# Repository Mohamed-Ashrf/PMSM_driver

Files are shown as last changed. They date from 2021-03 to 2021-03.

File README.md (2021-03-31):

# PMSM_driver
micro-controller based driver for PMSM and BLDC motors
# PMSM_driver
micro-controller based driver for PMSM and BLDC motors

# main components 
  1- STM32f446RE as main micro controller.
  2- DRV8323H as the moset driver and integrated curent sensor.
  3- CSD19534Q5A, a 100V rated mosfets.
  
# main functions
this driver is mainly a three phase inverter, so it can be used to drive ay three phase machie within the range of 60V or less (maily for 48V systems), it also can be used as an H-bridge by utilizig onlt two phases, the main PCB has an interface for encoder to be used in acuators, the driver also provides 12V 1.5A output.

# BETA
the hardware is still under testig so soon the main version will be uploaded plus the code for interfacing with the driver, mainly Six-step commutation ad FOC will be implemented.

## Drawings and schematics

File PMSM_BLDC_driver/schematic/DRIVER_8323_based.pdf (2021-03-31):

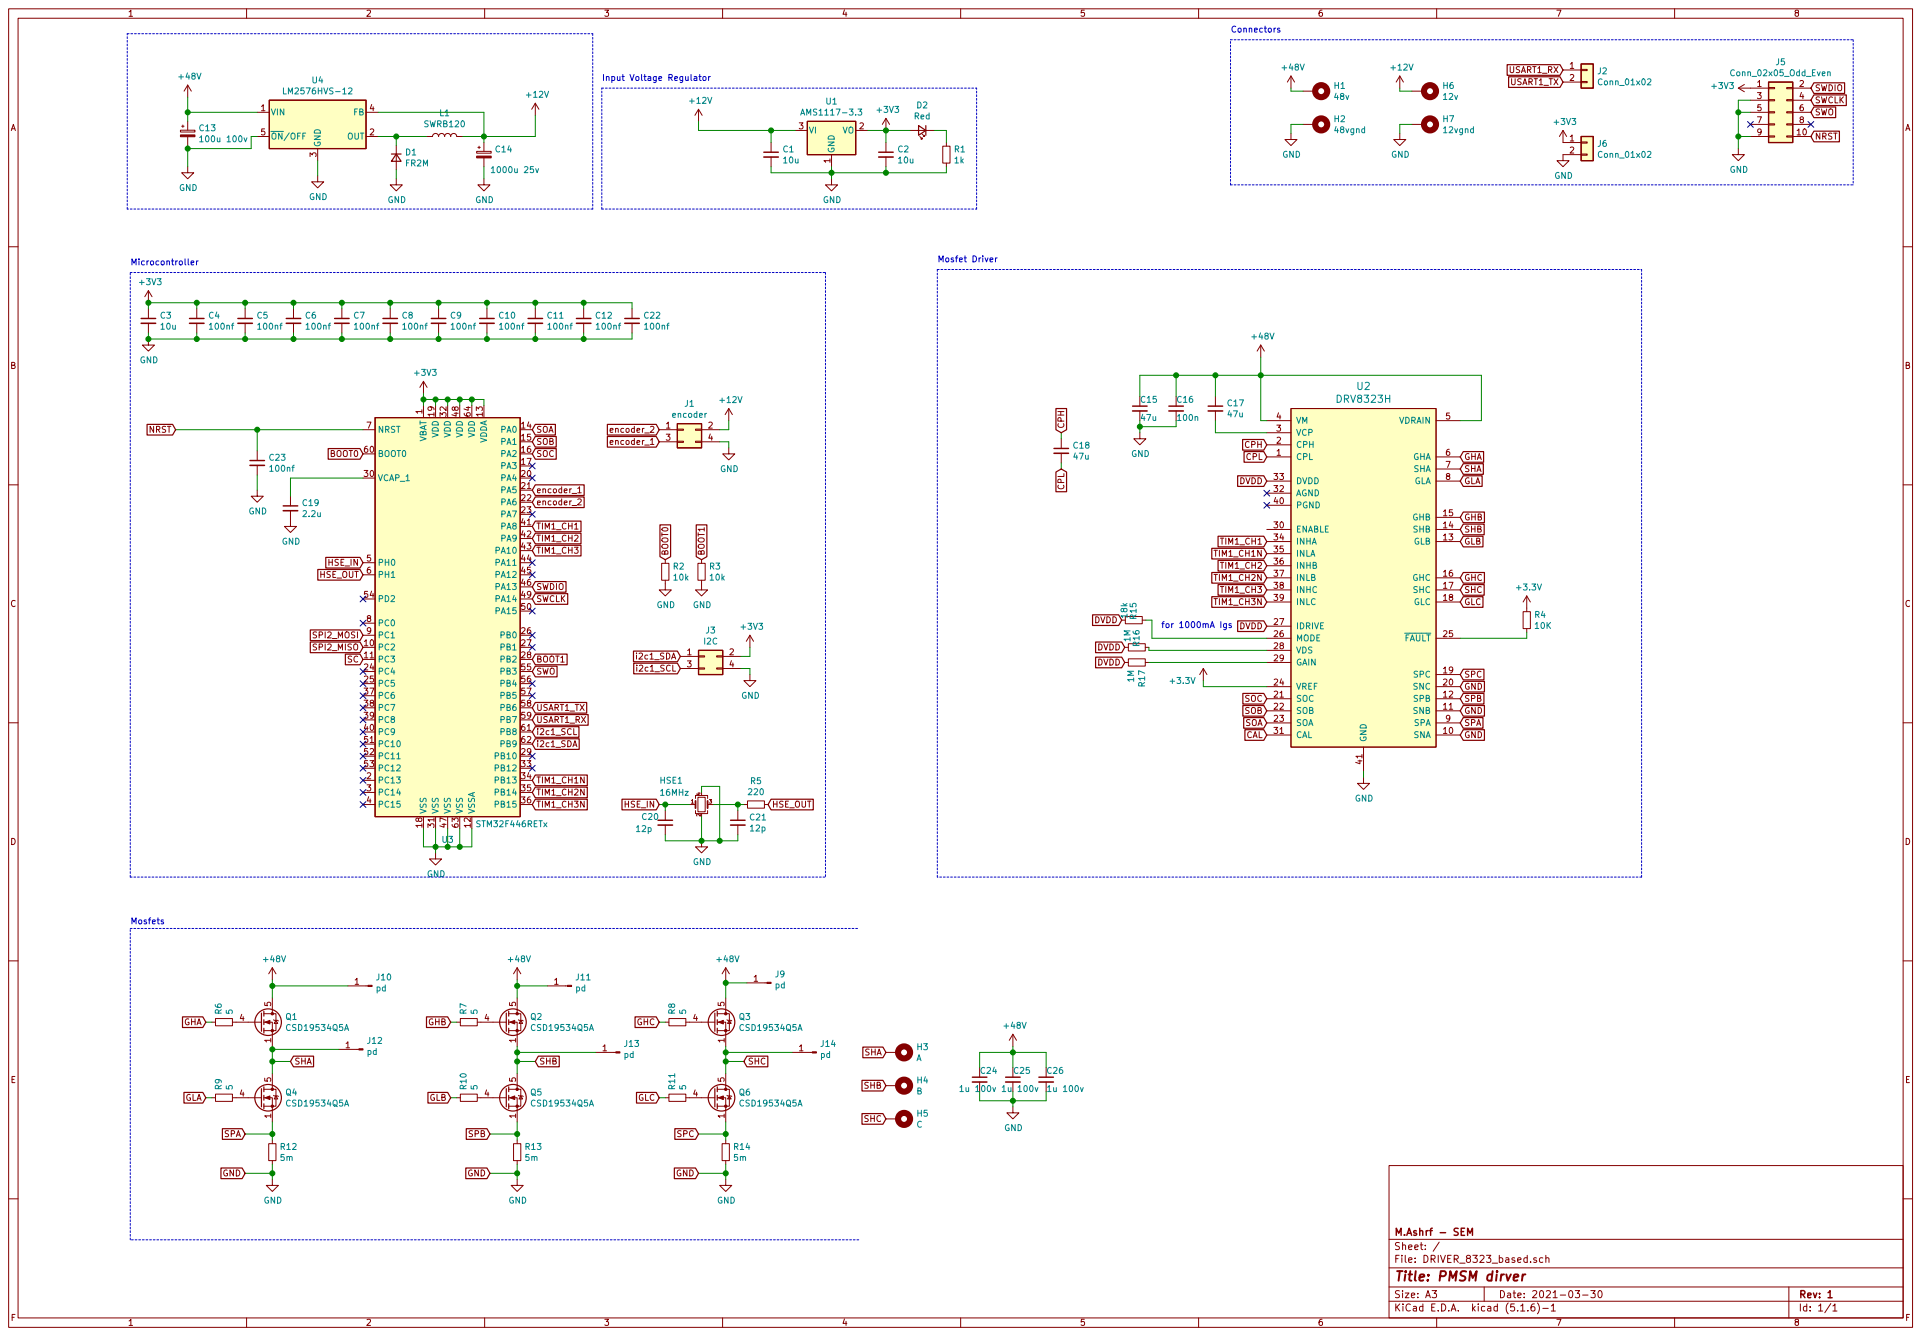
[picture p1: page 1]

7 9 | 8

1 VCAP_1 30 VDD 19 VDD 32 VDD 48 VDD 64 VDDA 13 VSS 18 VSS 31 VSS 47 VSS 63 VSSA 12 U3 STM32F446RETx GND

Id: 1/1 Title: PMSM dirver

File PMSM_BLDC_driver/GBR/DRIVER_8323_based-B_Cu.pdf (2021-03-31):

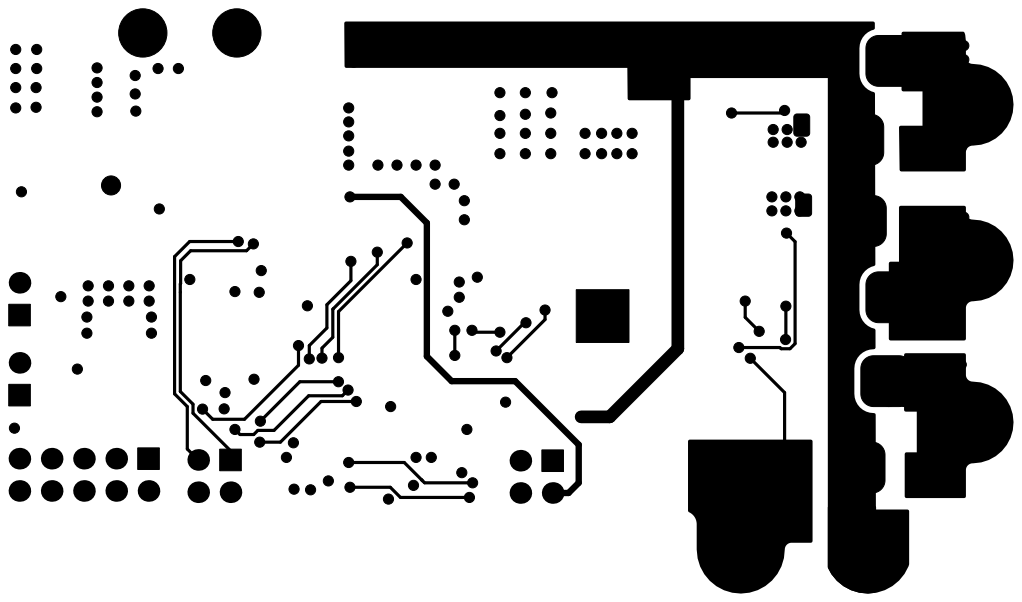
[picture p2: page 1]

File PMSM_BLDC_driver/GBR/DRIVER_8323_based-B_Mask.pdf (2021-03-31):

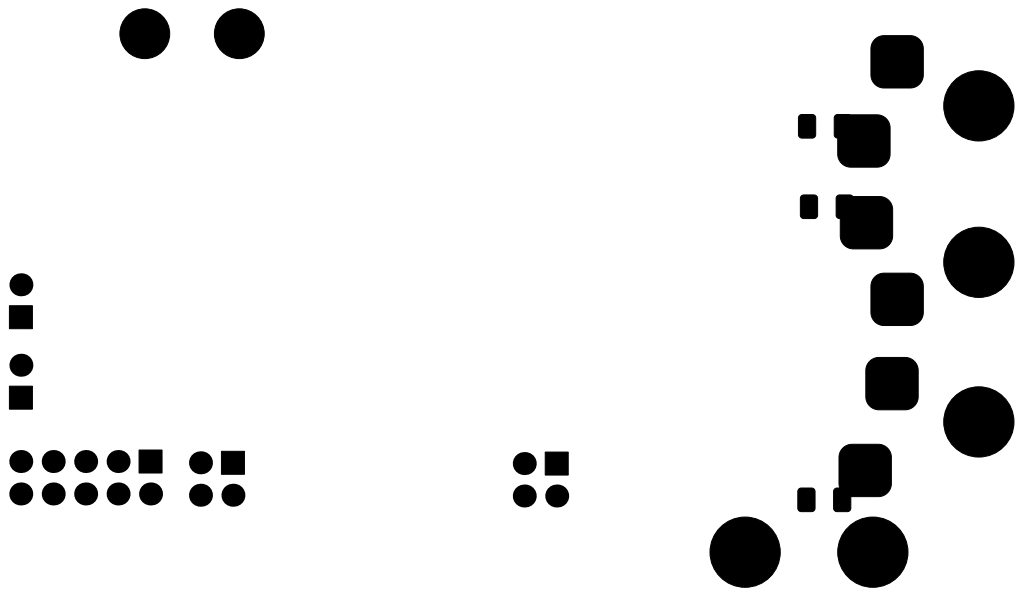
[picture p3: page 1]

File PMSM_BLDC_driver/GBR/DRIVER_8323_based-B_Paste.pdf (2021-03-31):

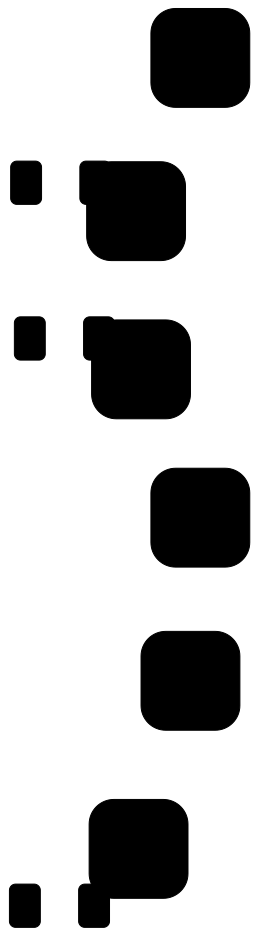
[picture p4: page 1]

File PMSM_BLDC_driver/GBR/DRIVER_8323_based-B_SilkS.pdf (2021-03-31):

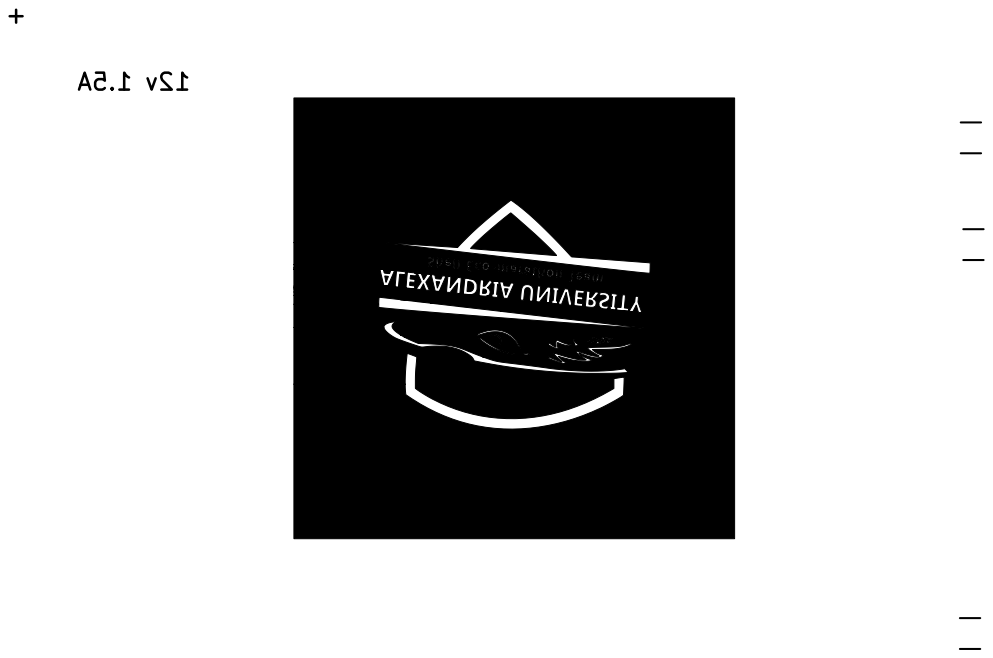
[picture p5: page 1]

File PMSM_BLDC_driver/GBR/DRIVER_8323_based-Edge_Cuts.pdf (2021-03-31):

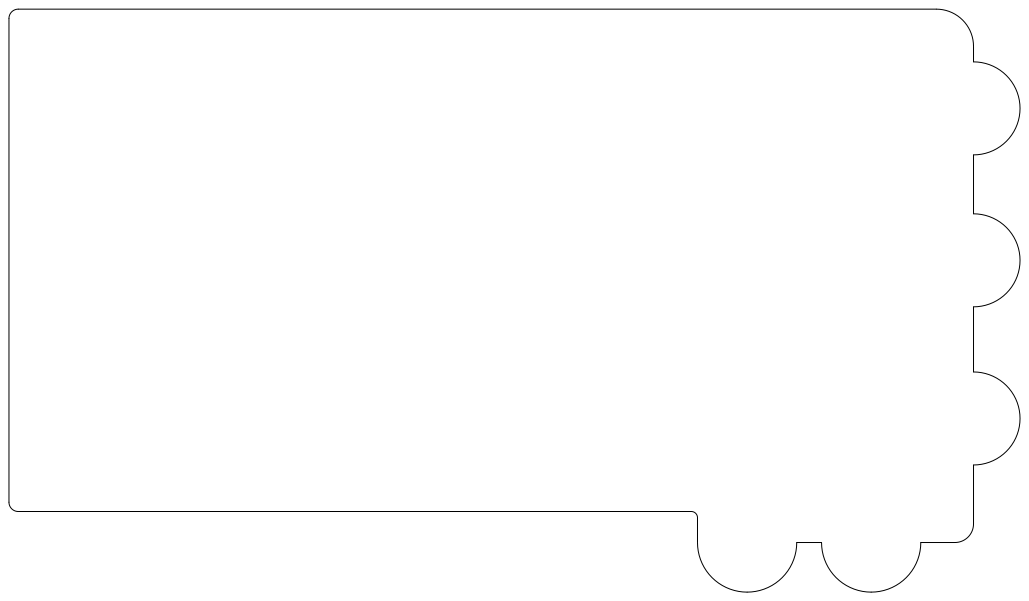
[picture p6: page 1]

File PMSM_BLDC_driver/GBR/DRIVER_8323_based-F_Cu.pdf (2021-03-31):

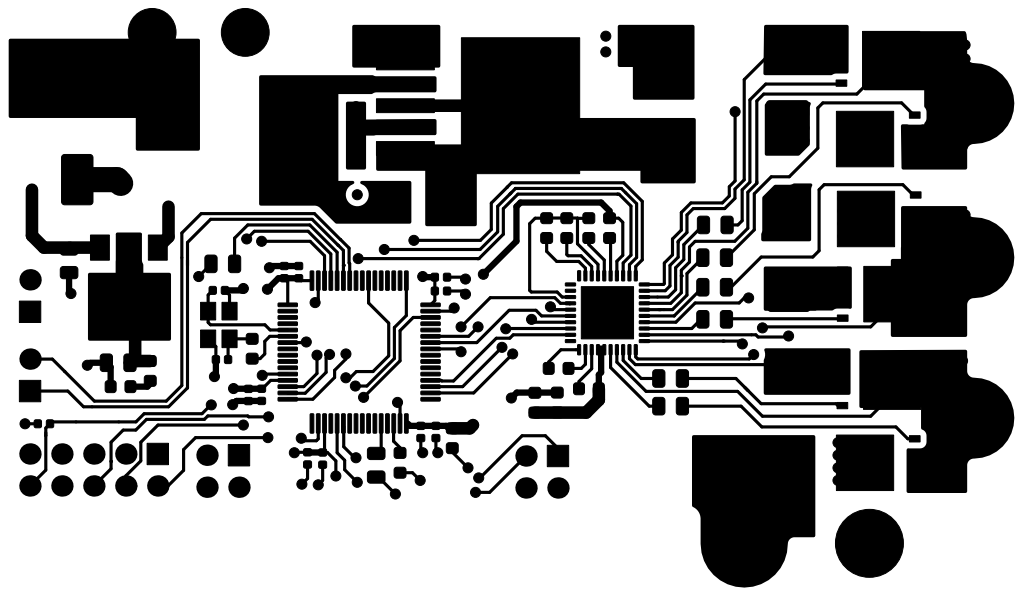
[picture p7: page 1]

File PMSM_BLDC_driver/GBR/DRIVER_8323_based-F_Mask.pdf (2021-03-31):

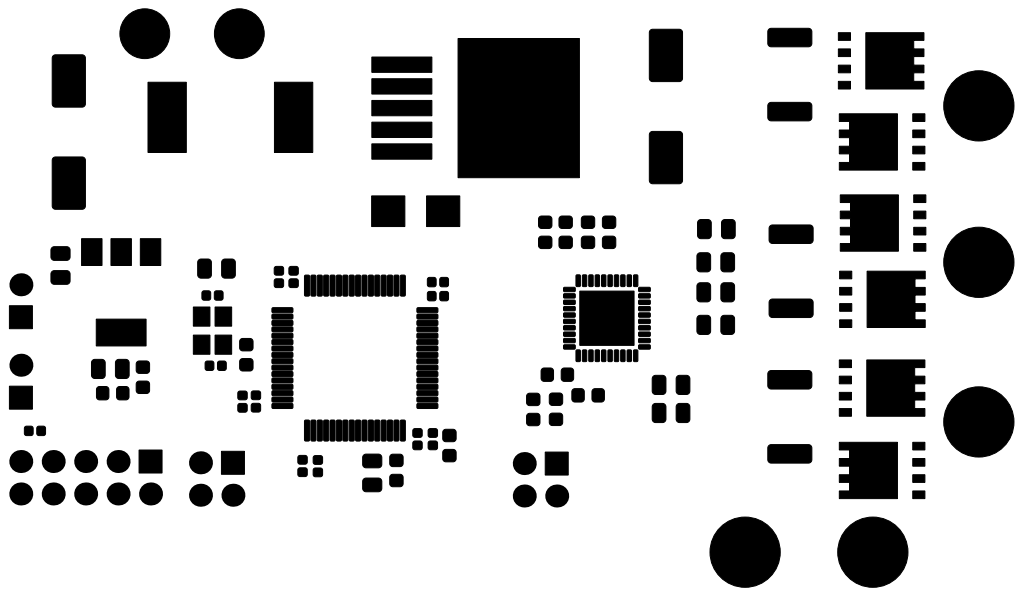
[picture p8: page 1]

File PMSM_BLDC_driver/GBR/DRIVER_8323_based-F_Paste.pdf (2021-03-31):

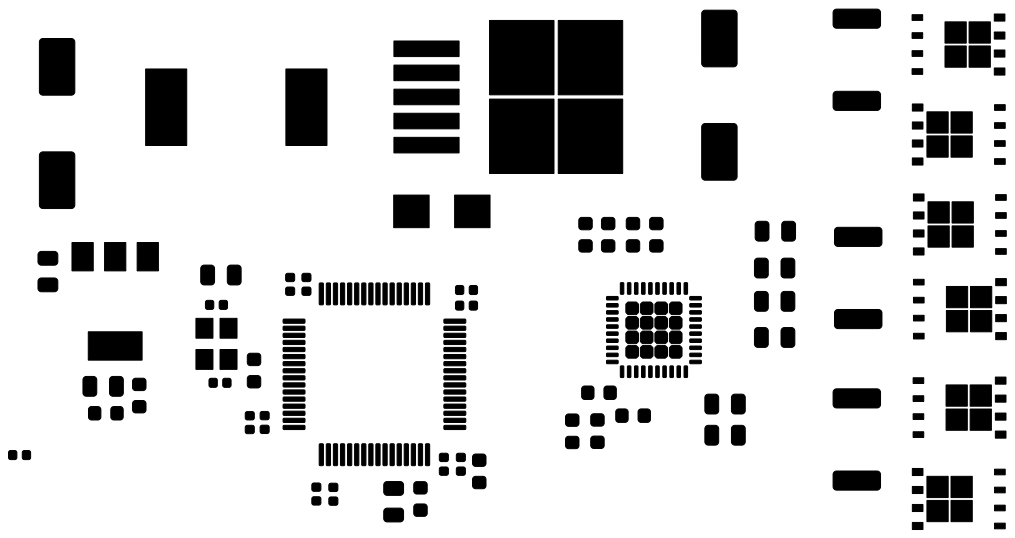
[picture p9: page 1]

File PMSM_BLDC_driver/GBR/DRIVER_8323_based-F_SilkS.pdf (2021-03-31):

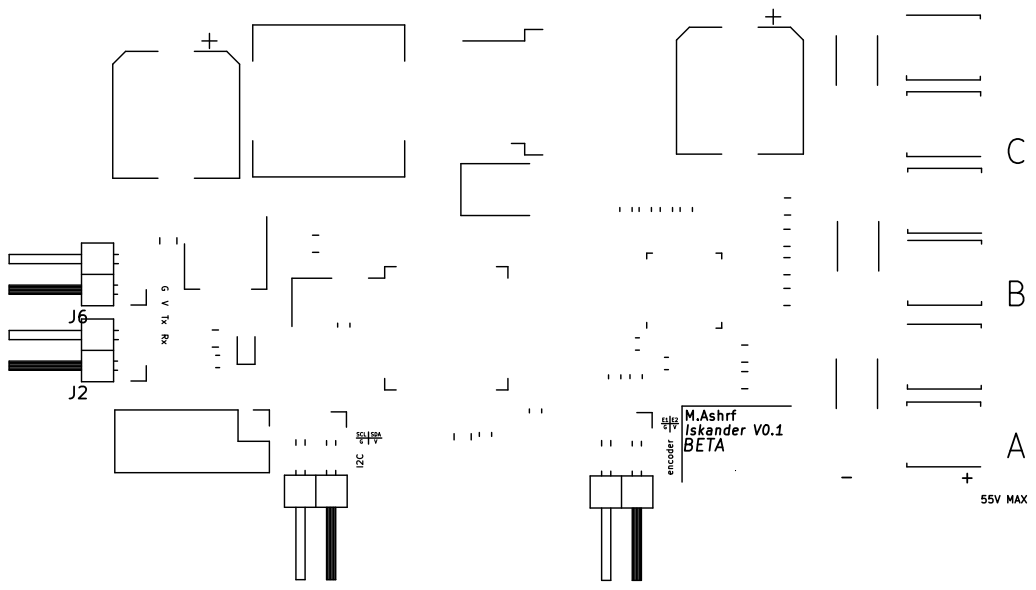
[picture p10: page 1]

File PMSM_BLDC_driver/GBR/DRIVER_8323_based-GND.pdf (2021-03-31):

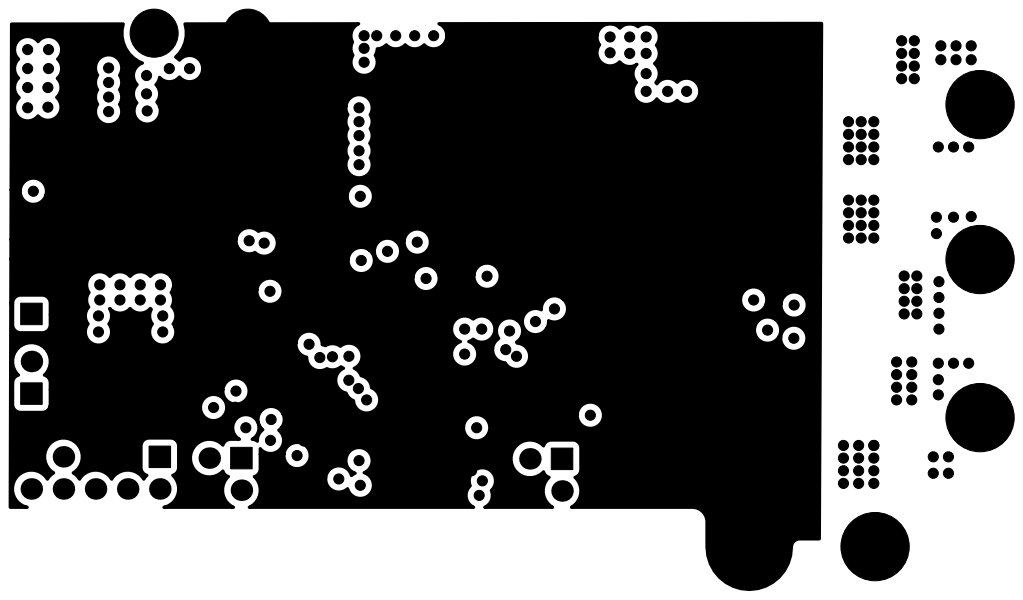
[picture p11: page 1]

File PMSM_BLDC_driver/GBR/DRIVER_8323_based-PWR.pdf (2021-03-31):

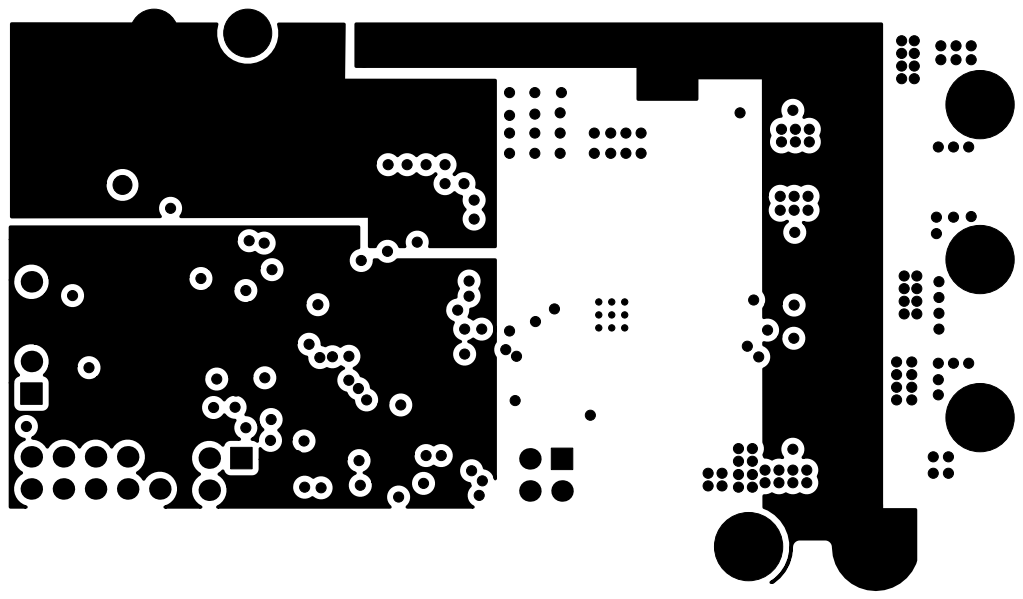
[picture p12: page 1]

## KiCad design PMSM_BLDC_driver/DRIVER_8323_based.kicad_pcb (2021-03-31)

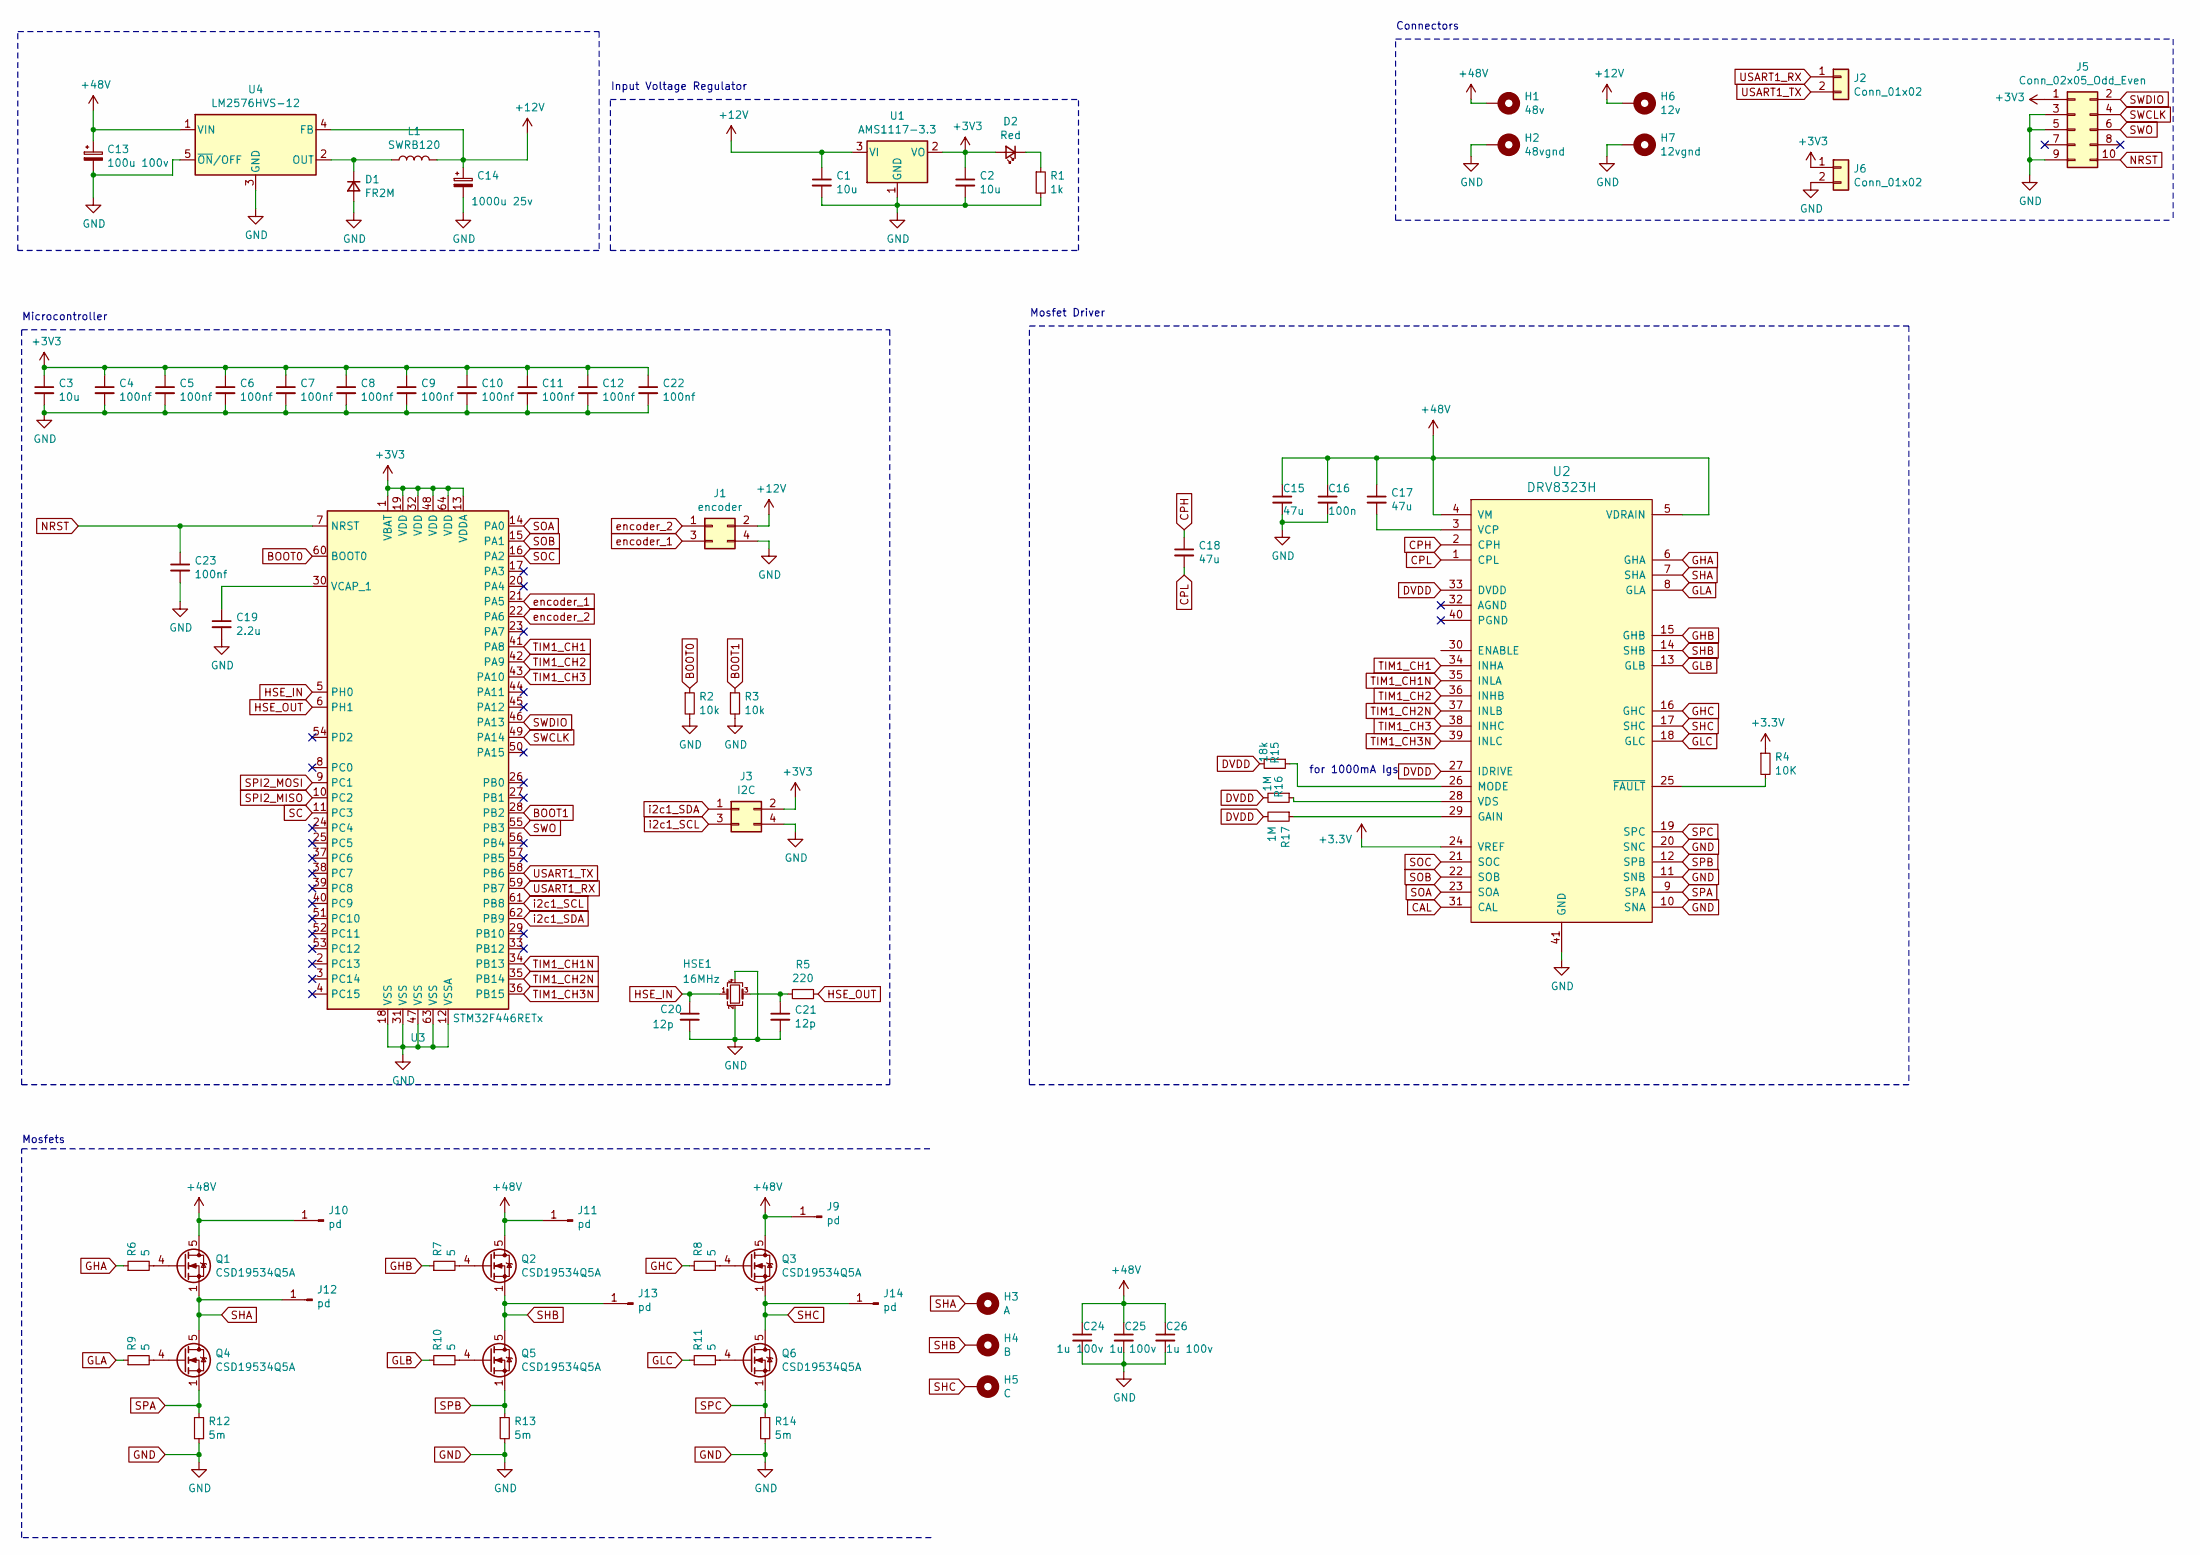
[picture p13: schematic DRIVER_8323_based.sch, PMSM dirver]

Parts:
C1, C2: 10u; C_0805_2012Metric
C3: 10u; C_0603_1608Metric
C4, C5, C6, C7, C8, C9, C10, C11, C12, C22, C23: 100nf; C_0402_1005Metric
C13: 100u 100v; CP_Elec_10x10
C14: 1000u 25v; CP_Elec_10x10
C15, C17, C18: 47u; C_0603_1608Metric
C16: 100n; C_0603_1608Metric
C19: 2.2u; C_0603_1608Metric
C20, C21: 12p; C_0402_1005Metric
C24, C25, C26: 1u 100v; C_1206_3216Metric
D1: FR2M; D_SMB
D2: Red; LED_0603_1608Metric
H1: 48v; MountingHole_2.7mm_Pad
H2: 48vgnd; MountingHole_2.7mm_Pad
H3: A; MountingHole_2.7mm_Pad
H4: B; MountingHole_2.7mm_Pad
H5: C; MountingHole_2.7mm_Pad
H6: 12v; MountingHole_2.2mm_M2_DIN965_Pad
H7: 12vgnd; MountingHole_2.2mm_M2_DIN965_Pad
HSE1: 16MHz; Crystal_SMD_3225-4Pin_3.2x2.5mm
J1: encoder; PinHeader_2x02_P2.54mm_Horizontal
J2, J6: Conn_01x02; PinHeader_1x02_P2.54mm_Horizontal
J3: I2C; PinHeader_2x02_P2.54mm_Horizontal
J5: Conn_02x05_Odd_Even; PinHeader_2x05_P2.54mm_Vertical
J9, J10, J11, J12, J13, J14: pd; SolderWirePad_1x01_SMD_1x2mm
L1: SWRB120; L_12x12mm_H4.5mm
Q1, Q2, Q3, Q4, Q5, Q6: CSD19534Q5A; TDSON-8-1
R1: 1k; R_0603_1608Metric
R2, R3: 10k; R_0805_2012Metric
R4: 10K; R_0603_1608Metric
R5: 220; R_0603_1608Metric
R6, R7, R8, R9, R10, R11: 5; R_0805_2012Metric
R12, R13, R14: 5m; R_2512_6332Metric
R15: 18k; R_0603_1608Metric
R16, R17: 1M; R_0603_1608Metric
U1: AMS1117-3.3; SOT-223-3_TabPin2
U2: DRV8323H; QFN-40-1EP_6x6mm_P0.5mm_EP4.6x4.6mm_ThermalVias
U3: STM32F446RETx; LQFP-64_10x10mm_P0.5mm
U4: LM2576HVS-12; TO-263-5_TabPin3

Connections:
+12V: C1.1, C14.1, H6.1, J1.2, L1.2, U1.3 (VI), U4.4 (FB)
+48V: C13.1, C15.1, C16.1, C17.1, C24.1, C25.1, C26.1, H1.1, J9.1, J10.1, J11.1, Q1.5 (D), Q2.5 (D), Q3.5 (D), U2.4 (VM), U2.5 (VDRAIN), U4.1 (VIN)
BOOT0: R2.1, U3.60 (BOOT0)
BOOT1: R3.1, U3.28 (PB2)
CAL: U2.31 (CAL)
CPH: C18.1, U2.2 (CPH)
CPL: C18.2, U2.1 (CPL)
DVDD: R15.2, R16.2, R17.2, U2.27 (IDRIVE), U2.33 (DVDD)
GHA: R6.1, U2.6 (GHA)
GHB: R7.1, U2.15 (GHB)
GHC: R8.1, U2.16 (GHC)
GLA: R9.1, U2.8 (GLA)
GLB: R10.1, U2.13 (GLB)
GLC: R11.1, U2.18 (GLC)
GND: C1.2, C2.2, C3.2, C4.2, C5.2, C6.2, C7.2, C8.2, C9.2, C10.2, C11.2, C12.2, C13.2, C14.2, C15.2, C16.2, C19.2, C20.2, C21.2, C22.2, C23.2, C24.2, C25.2, C26.2, D1.2 (A), H2.1, H7.1, HSE1.2, HSE1.4, J1.4, J3.4, J5.3, J5.5, J5.9, J6.2, R1.2, R2.2, R3.2, R12.2, R13.2, R14.2, U1.1 (GND), U2.10 (SNA), U2.11 (SNB), U2.20 (SNC), U2.41 (GND), U3.12 (VSSA), U3.18 (VSS), U3.31 (VSS), U3.47 (VSS), U3.63 (VSS), U4.3 (GND), U4.5 (~ON~/OFF)
HSE_IN: C20.1, HSE1.1, U3.5 (PH0)
HSE_OUT: R5.1, U3.6 (PH1)
NRST: C23.1, J5.10, U3.7 (NRST)
unnamed: C17.2, U2.3 (VCP)
unnamed: C19.1, U3.30 (VCAP_1)
unnamed: C21.1, HSE1.3, R5.2
unnamed: D1.1 (K), L1.1, U4.2 (OUT)
unnamed: D2.1 (K), R1.1
unnamed: Q1.4 (G), R6.2
unnamed: Q2.4 (G), R7.2
unnamed: Q3.4 (G), R8.2
unnamed: Q4.4 (G), R9.2
unnamed: Q5.4 (G), R10.2
unnamed: Q6.4 (G), R11.2
unnamed: R4.2, U2.25 (~FAULT)
unnamed: R15.1, U2.26 (MODE)
unnamed: R16.1, U2.28 (VDS)
unnamed: R17.1, U2.29 (GAIN)
SC: U3.11 (PC3)
SHA: H3.1, J12.1, Q1.1 (S), Q1.2 (S), Q1.3 (S), Q4.5 (D), U2.7 (SHA)
SHB: H4.1, J13.1, Q2.1 (S), Q2.2 (S), Q2.3 (S), Q5.5 (D), U2.14 (SHB)
SHC: H5.1, J14.1, Q3.1 (S), Q3.2 (S), Q3.3 (S), Q6.5 (D), U2.17 (SHC)
SOA: U2.23 (SOA), U3.14 (PA0)
SOB: U2.22 (SOB), U3.15 (PA1)
SOC: U2.21 (SOC), U3.16 (PA2)
SPA: Q4.1 (S), Q4.2 (S), Q4.3 (S), R12.1, U2.9 (SPA)
SPB: Q5.1 (S), Q5.2 (S), Q5.3 (S), R13.1, U2.12 (SPB)
SPC: Q6.1 (S), Q6.2 (S), Q6.3 (S), R14.1, U2.19 (SPC)
SPI2_MISO: U3.10 (PC2)
SPI2_MOSI: U3.9 (PC1)
SWCLK: J5.4, U3.49 (PA14)
SWDIO: J5.2, U3.46 (PA13)
SWO: J5.6, U3.55 (PB3)
TIM1_CH1: U2.34 (INHA), U3.41 (PA8)
TIM1_CH1N: U2.35 (INLA), U3.34 (PB13)
TIM1_CH2: U2.36 (INHB), U3.42 (PA9)
TIM1_CH2N: U2.37 (INLB), U3.35 (PB14)
TIM1_CH3: U2.38 (INHC), U3.43 (PA10)
TIM1_CH3N: U2.39 (INLC), U3.36 (PB15)
USART1_RX: J2.1, U3.59 (PB7)
USART1_TX: J2.2, U3.58 (PB6)
encoder_1: J1.3, U3.21 (PA5)
encoder_2: J1.1, U3.22 (PA6)
i2c1_SCL: J3.3, U3.61 (PB8)
i2c1_SDA: J3.1, U3.62 (PB9)

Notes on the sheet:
Input Voltage Regulator
Microcontroller
Connectors
Mosfet Driver
for 1000mA Igs
Mosfets

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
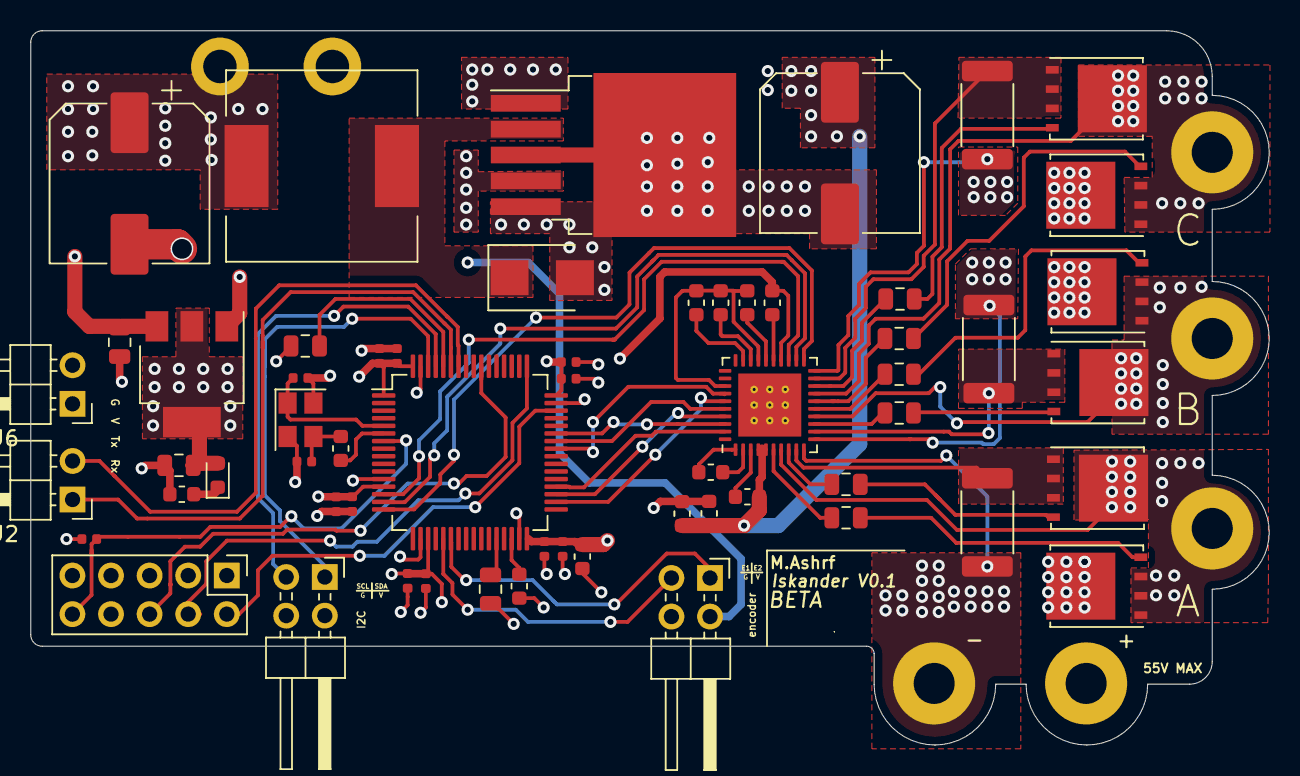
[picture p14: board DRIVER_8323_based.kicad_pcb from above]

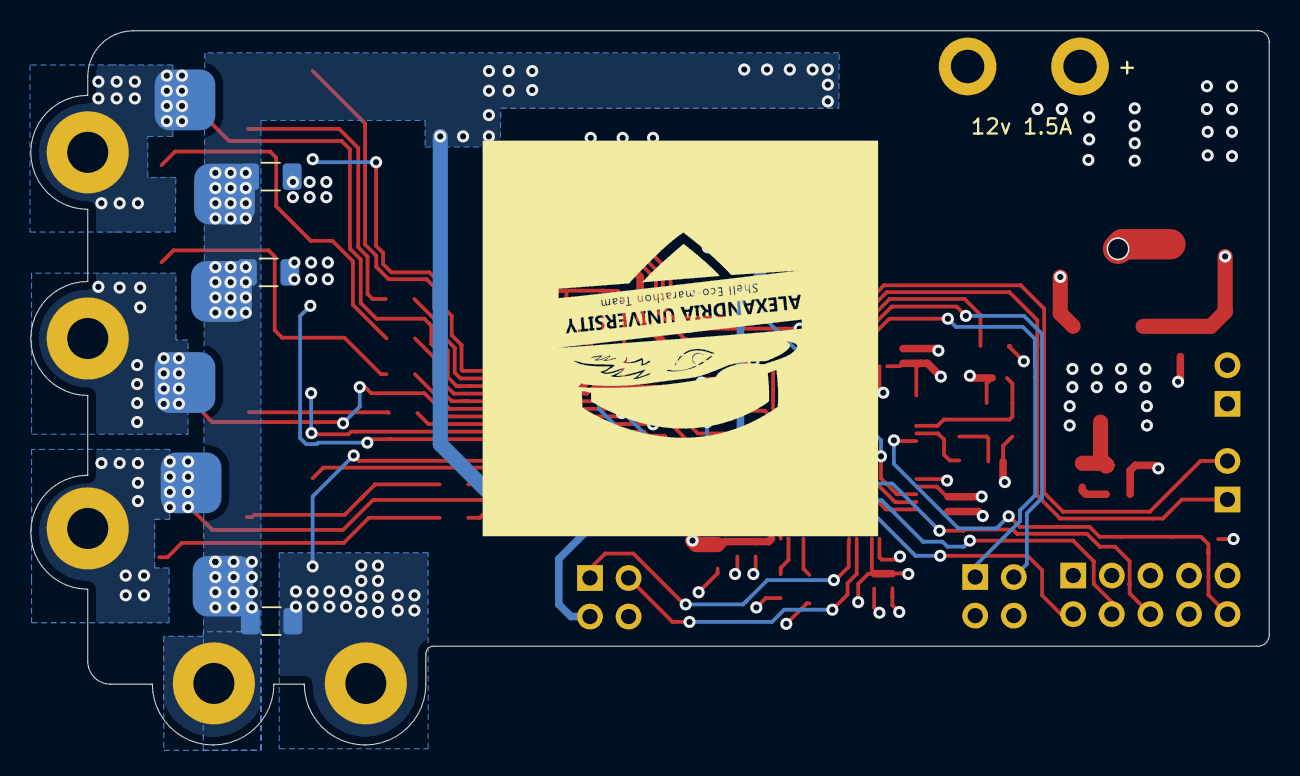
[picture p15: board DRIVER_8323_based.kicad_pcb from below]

Board: 4 copper layers, 81.5 x 47.0 mm, 75 parts (11 on the bottom side), 57 nets.
